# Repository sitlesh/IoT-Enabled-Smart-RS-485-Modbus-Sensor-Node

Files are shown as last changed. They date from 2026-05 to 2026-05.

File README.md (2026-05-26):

# IoT-Enabled-Smart-RS-485-Modbus-Sensor-Node
Industrial-grade Modbus RTU communication node featuring full galvanic isolation between the ATmega328P logic block and the RS485 network. Designed in KiCad with an optimized on-board LM2596 switching buck regulator. 100% DRC clean.
# Through-Hole Isolated Modbus Board

An industrial-grade, highly reliable Modbus RTU communication hardware platform designed using KiCad. This board acts as a robust node (Master/Slave) in harsh electrical environments, incorporating comprehensive galvanic isolation between the microcontroller logic block and the external RS485 network to safeguard against high-voltage surges, ground loops, and electromagnetic interference (EMI).

---

## 📸 Project Previews

### 1. 3D Renders
| 3D Render - Front View | 3D Render - Back View |
|---|---|
| IoT-Enabled Smart RS-485 Modbus Sensor Node | IoT-Enabled Smart RS-485 Modbus Sensor Node back |

### 2. 2D PCB Routing Layout (Layer-by-Layer)
Here is the detailed 2-layer routing layout. You can clearly see the physical separation gap that maintains true galvanic isolation between the two grounds.

| Top Layer Routing (F.Cu - Red) | Bottom Layer Routing (B.Cu - Blue) |
|---|---|
| Screenshot (24) | Screenshot (25) |
---

## 🛠️ Detailed Technical Specifications

### 1. Core Logic & Processing Block
- **Microcontroller:** Microchip ATmega328P-PU (28-pin DIP package for easy through-hole assembly/swapping).
- **Clock Configuration:** External 16 MHz quartz crystal oscillator (`Y1`) stabilized by dual 22pF ceramic load capacitors (`C3`, `C4`) positioned with minimal trace lengths to mitigate high-frequency parasitic layout loop noise.
- **In-System Programming:** Dedicated breakout pins for standard FTDI/UART flashing and debug interfaces.

### 2. Galvanic Isolation Architecture (Dual Plane Separation)
To achieve true industrial-grade isolation, the board is split into two completely distinct galvanic zones divided by a physical isolation trench across the PCB layout:
- **Logic Zone (Safe Side):** Powered by the local regulator system. Houses the ATmega328P, crystal oscillator, and logic-side optocoupler interfaces. Operating on standard `GNDPWR` ground.
- **Bus Zone (Isolated Side):** Completely isolated from the main logic power supply. Houses the MAX485 transceiver, biased pull-up/pull-down safety networks, and external communication lines. Operating on isolated `GNDD` ground.
- **Signal Opto-coupling:** Dual high-speed optocouplers (`PC817`) handle bidirectional UART data flow ($TX$ and $RX$). 
  - `U4` isolates transmission signals going from the MCU to the transceiver.
  - `U3` isolates receiving network data going from the transceiver back to the MCU.

### 3. Power Supply & Regulation Block
- **Topology:** Step-down switching buck regulator circuit utilizing the **LM2596T-5** IC to step down standard industrial 12V/24V DC inputs down to a stable 5V rail.
- **Input Filtering & Protection:** Reverse polarity protection diode (`D1` - 1N4007) paired with a high-capacity polarized input electrolytic smoothing capacitor (`Cin1`).
- **Power Loop Optimization:** Low-loop-inductance component placement topology linking the input capacitor, switching regulator output pin, fast-recovery Schottky catch diode (`D2` - 1N5822), power inductor (`L1`), and output filtering capacitor (`Cout1`) linearly to dramatically minimize switching EMI.

### 4. RS485 Modbus Interface
- **Transceiver:** Maxim Integrated **MAX485E** low-power transceiver for RS485 communication.
- **Bus Termination:** On-board standard $120\Omega$ termination resistor (`R5`) bridging the differential $A$ and $B$ communication lines to eliminate signal reflections over long cable distances.
- **Connectors:** Heavy-duty screw terminals (`J1` for main DC power input, `J2` for differential $A/B$ Modbus lines) accommodating industrial wiring configurations.

---

## 📐 PCB Layout Design Parameters

- **EDA Tool:** KiCad 10.0
- **Form Factor Dimensions:** $80\text{mm} \times 50\text{mm}$
- **Layer Count:** 2 Layers (Top Layer: Signals & Linear Power Paths / Bottom Layer: Split Solid Ground Planes for optimal shielding).
- **Track Routing Guidelines:** - Signal Traces: `0.30mm` to `0.40mm` width for tight digital density.
  - High-Current Power Traces: `0.80mm` to `1.00mm` width to ensure minimal voltage drops and lower thermal resistance.
  - Geometry: Strict usage of $45^\circ$ angles to eliminate current crowding and signal distortion.
- **Design Rule Verification:** 100% DRC (Design Rule Check) compliant with **0 Errors** and **0 Warnings**.

---

## 📁 Repository Directory Structure

This repository contains all the native design assets and manufacturing files required to replicate or modify this project.

### 🛠️ Core EDA Design Files (KiCad 8.0)
* **[`IoT-Enabled Smart RS-485 Modbus Sensor Node.kicad_pro`](./IoT-Enabled%20Smart%20RS-485%20Modbus%20Sensor%20Node.kicad_pro)** - Master KiCad project management file.
* **[`IoT-Enabled Smart RS-485 Modbus Sensor Node.kicad_sch`](./IoT-Enabled%20Smart%20RS-485%20Modbus%20Sensor%20Node.kicad_sch)** - Schematic capture detailing logical nets, MCU connections, power regulation, and RS-485 transceiver circuitry.
* **[`IoT-Enabled Smart RS-485 Modbus Sensor Node.kicad_pcb`](./IoT-Enabled%20Smart%20RS-485%20Modbus%20Sensor%20Node.kicad_pcb)** - Physical 2-layer PCB layout with optimized component positioning, power loops, and differential pairs.

### 📦 Manufacturing & Fabrication Outputs
* **[`Gerbers/`](./Gerbers)** - Directory containing production-ready, compressed industrial manufacturing files (Gerbers and NC Drill data) formatted for immediate submission to fabrication houses (e.g., JLCPCB, PCBWay).

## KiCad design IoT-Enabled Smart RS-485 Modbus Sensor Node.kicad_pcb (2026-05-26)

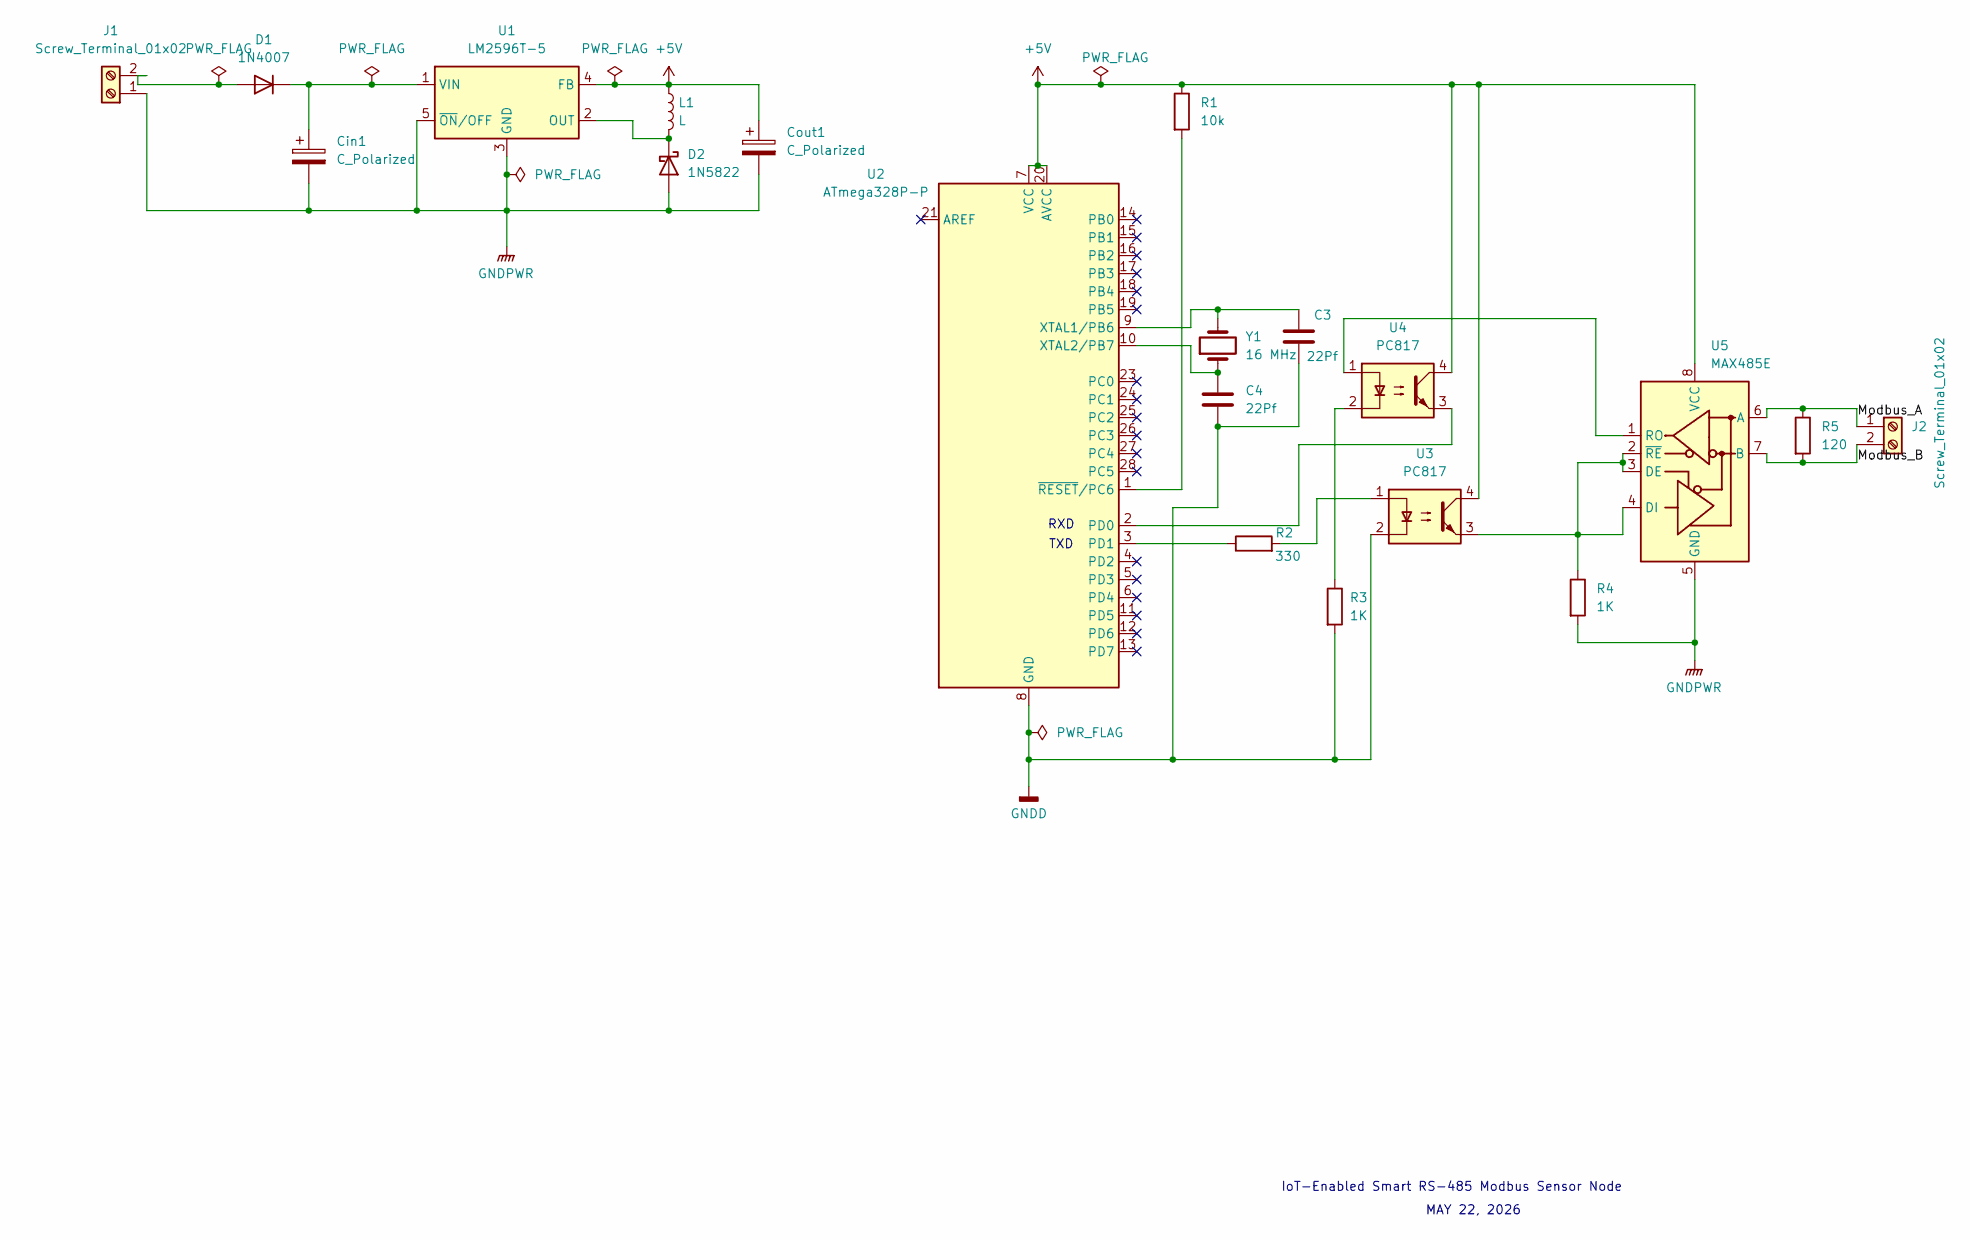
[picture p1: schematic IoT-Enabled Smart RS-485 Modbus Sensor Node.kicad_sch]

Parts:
C3, C4: 22Pf; C_Disc_D3.8mm_W2.6mm_P2.50mm
Cin1: C_Polarized; CP_Radial_D10.0mm_P5.00mm
Cout1: C_Polarized; CP_Radial_D10.0mm_P5.00mm
D1: 1N4007; D_DO-41_SOD81_P10.16mm_Horizontal
D2: 1N5822; D_DO-201AD_P15.24mm_Horizontal
J1, J2: Screw_Terminal_01x02; TerminalBlock_Phoenix_PT-1,5-2-5.0-H_1x02_P5.00mm_Horizontal
L1: L; L_Radial_D10.0mm_P5.00mm_Fastron_07M
R1: 10k; R_Axial_DIN0207_L6.3mm_D2.5mm_P10.16mm_Horizontal
R2: 330; R_Axial_DIN0207_L6.3mm_D2.5mm_P10.16mm_Horizontal
R3, R4: 1K; R_Axial_DIN0207_L6.3mm_D2.5mm_P10.16mm_Horizontal
R5: 120; R_Axial_DIN0207_L6.3mm_D2.5mm_P10.16mm_Horizontal
U1: LM2596T-5; TO-220-5_P3.4x3.7mm_StaggerOdd_Lead3.8mm_Vertical
U2: ATmega328P-P; DIP-28_W7.62mm
U3, U4: PC817; DIP-4_W7.62mm
U5: MAX485E; SOIC-8_3.9x4.9mm_P1.27mm
Y1: 16 MHz; Crystal_HC49-4H_Vertical

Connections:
+5V: Cout1.1, L1.1, R1.1, U1.4 (FB), U2.7 (VCC), U2.20 (AVCC), U3.4, U4.4, U5.8 (VCC)
/Modbus_A: J2.1, R5.1, U5.6 (A)
/Modbus_B: J2.2, R5.2, U5.7 (B)
GNDD: C3.2, C4.2, R3.2, U2.8 (GND), U2.22 (GND), U3.2
GNDPWR: Cin1.2, Cout1.2, D2.2 (A), J1.1, R4.2, U1.3 (GND), U1.5 (~ON/OFF), U5.5 (GND)
unnamed: D1.2 (A), J1.2
unnamed: Cin1.1, D1.1 (K), U1.1 (VIN)
unnamed: D2.1 (K), L1.2, U1.2 (OUT)
unnamed: R2.2, U3.1
unnamed: R3.1, U4.2
unnamed: U2.2 (PD0), U4.3
unnamed: R2.1, U2.3 (PD1)
unnamed: C3.1, U2.9 (XTAL1/PB6), Y1.2
unnamed: C4.1, U2.10 (XTAL2/PB7), Y1.1
unnamed: R1.2, U2.1 (~RESET/PC6)
unnamed: R4.1, U3.3, U5.2 (~RE), U5.3 (DE), U5.4 (DI)
unnamed: U4.1, U5.1 (RO)

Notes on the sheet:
RXD
TXD
MAY 22, 2026
IoT-Enabled Smart RS-485 Modbus Sensor Node

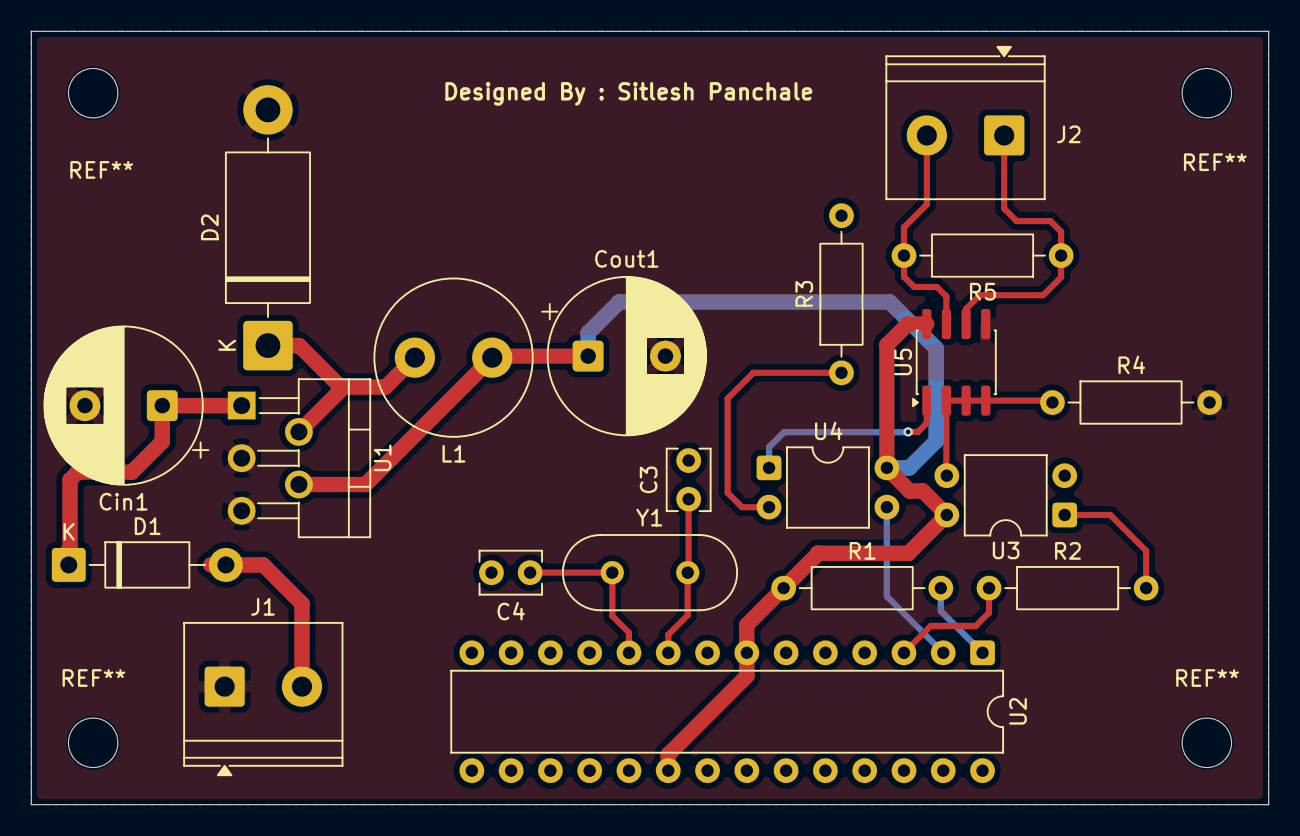
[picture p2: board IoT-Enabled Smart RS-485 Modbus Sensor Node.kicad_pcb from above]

Board: 2 copper layers, 80.0 x 50.0 mm, 20 parts (0 on the bottom side), 17 nets.
